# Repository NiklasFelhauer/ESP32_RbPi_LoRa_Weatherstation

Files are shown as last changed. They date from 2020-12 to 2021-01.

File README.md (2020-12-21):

# ESP32_RbPi_LoRa_Weatherstation

hey everyone!

components used: >1xESP32; >1xRaspberry Pi 4 Modell B; >1xBME280 weather sensor; >2xLoRa RFM95 tranceivers

IDE used: Visual Studio Code (Python: Microsoft Python Extension and C: PlatformIO Extension)

What is LoRa? LoRa (Long Range) is a upcoming RF technology that includes features like long range (depends highly on the area, but up to multiple miles) or low power consumption. So perfect for IoT projects like this one here!

description: ESP32 sends weather data (provided by BME280 sensor) via LoRa tranceiver to LoRa tranceiver (=connected to RbPi). Now, here are 2 directions to go: 1) RbPi sends weather data via MQTT network to NodeRed to display the data on a NodeRed dashboard OR 2) RbPi stores weather data in InflxDB (timestamps based database) to visualize the data in grafana

programming language used: mainly C (ESP32) and Python (Raspberry Pi) > (1) in NodeRed simple html, css, JAVA and JSON codes

planned updates: >3D-printed weatherstation case (I'll upload .stl data soon) >supply ESP32 with battery/solar-charger/solar-panel

more details in the specific folders.

stay tuned! :)

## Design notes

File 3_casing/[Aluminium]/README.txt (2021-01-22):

The .stl files for aluminum-components are just for visualization

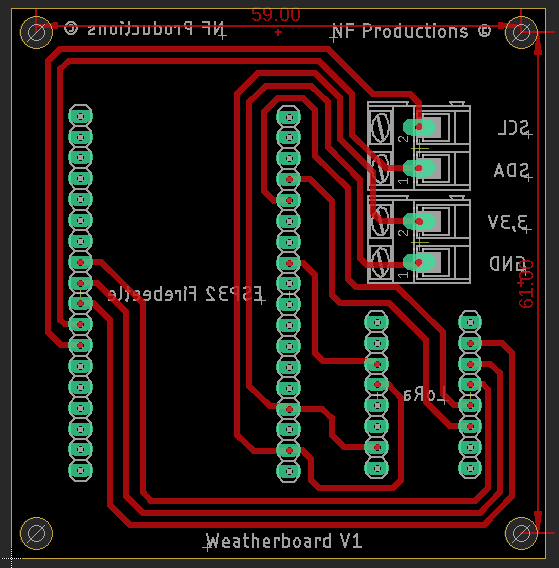
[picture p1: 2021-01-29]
4_circuit_board/Size.PNG

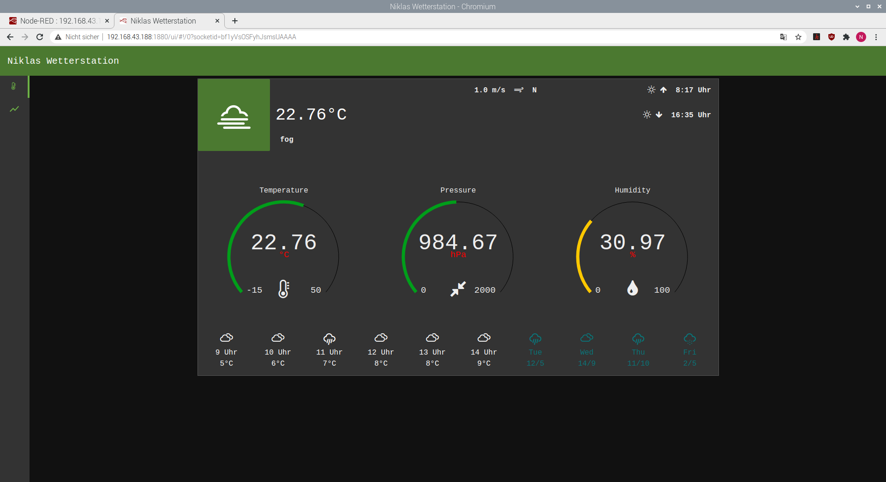
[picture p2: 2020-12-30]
2_MQTT_NodeRed/NodeRed (JSON,JAVA)/example_dashboard.png

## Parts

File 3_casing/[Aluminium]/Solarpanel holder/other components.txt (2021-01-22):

Screws:

x4: M5, 25mm
x1: M5, 30mm
x4: M4, 20mm

------------------

Nuts:

x5: M5

------------------

Aluminium Profiles used:

x2: 20x10x140mm
x1: 20x10x162mm

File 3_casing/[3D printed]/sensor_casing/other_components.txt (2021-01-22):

threaded rods:

x3: M5, 140mm length

Nuts:

x3: M5

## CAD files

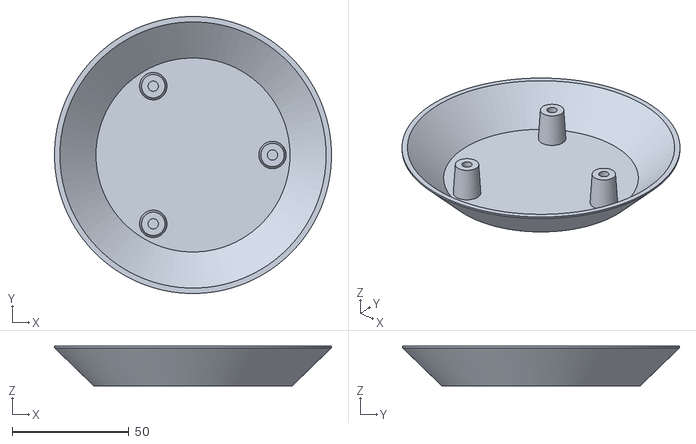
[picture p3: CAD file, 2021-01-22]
3_casing/[3D printed]/sensor_casing/__1x__main_top.stl
118.5 x 118.5 x 17.0

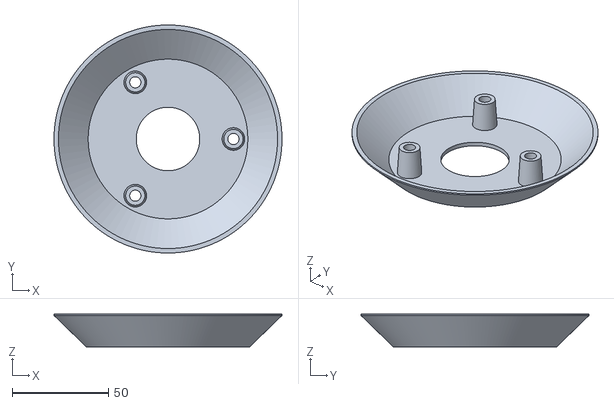
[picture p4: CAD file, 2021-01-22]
3_casing/[3D printed]/sensor_casing/__6x__main.stl
118.5 x 118.5 x 17.0

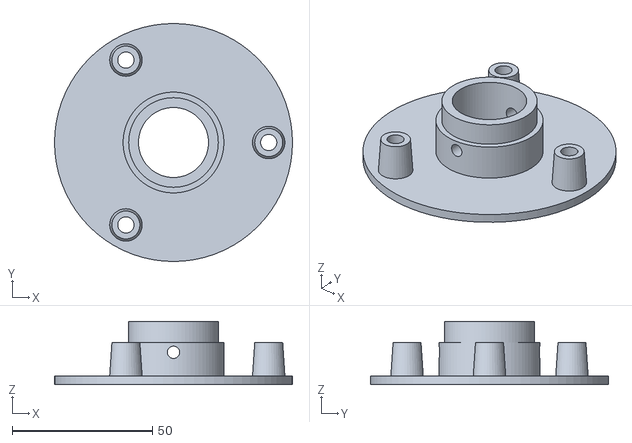
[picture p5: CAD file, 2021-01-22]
3_casing/[3D printed]/sensor_casing/__1x__main_bottom.stl
85.0 x 85.0 x 22.5

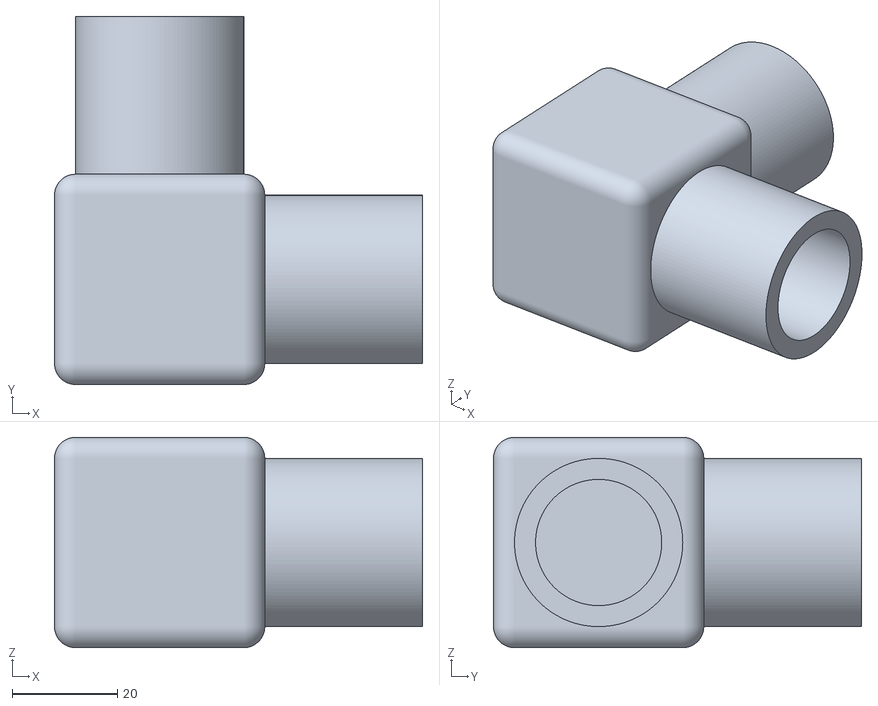
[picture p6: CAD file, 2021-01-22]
3_casing/[3D printed]/connectors/__1x__2_direction_connector.stl
70.0 x 70.0 x 40.0

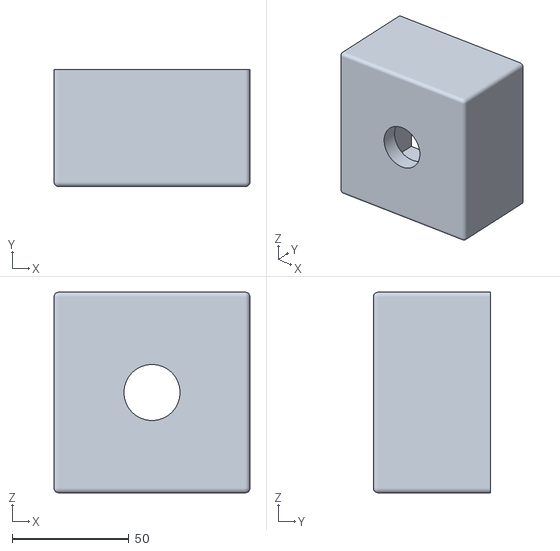
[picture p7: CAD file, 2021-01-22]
3_casing/[3D printed]/controlbox/NF_Box_1.stl
84.0 x 50.2 x 86.0

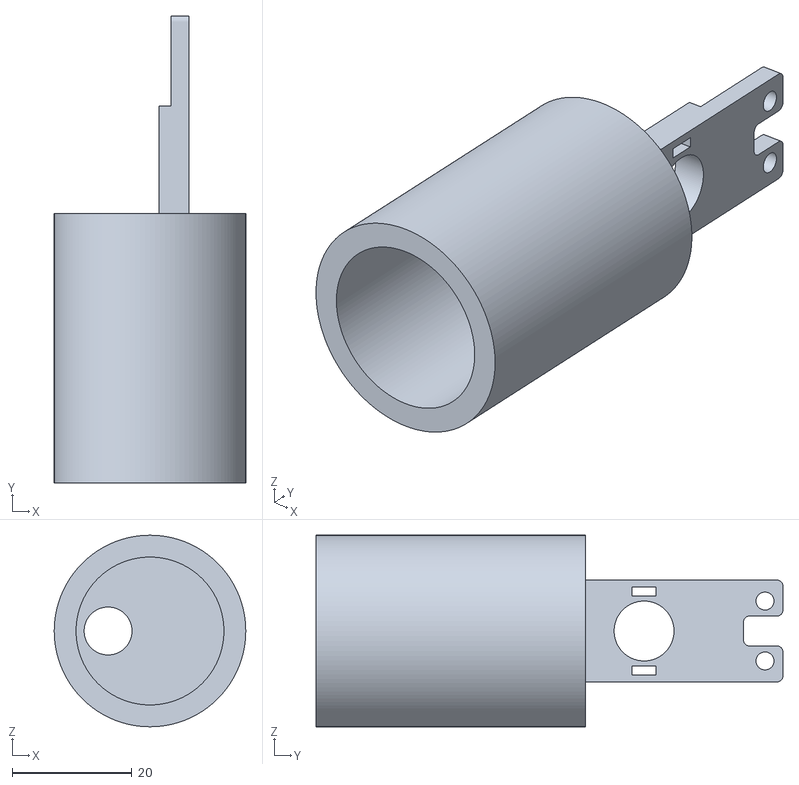
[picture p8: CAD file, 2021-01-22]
3_casing/[3D printed]/sensor_casing/__1x__Sensor_holder_V2.stl
32.0 x 78.0 x 32.0

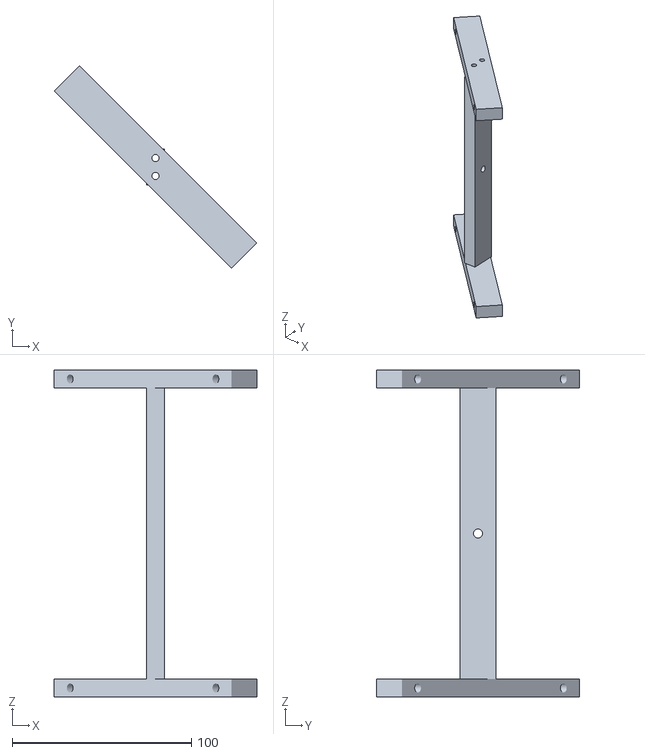
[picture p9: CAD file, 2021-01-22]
3_casing/[Aluminium]/Solarpanel holder/Solarpanel-holder.stl
113.1 x 113.1 x 182.5

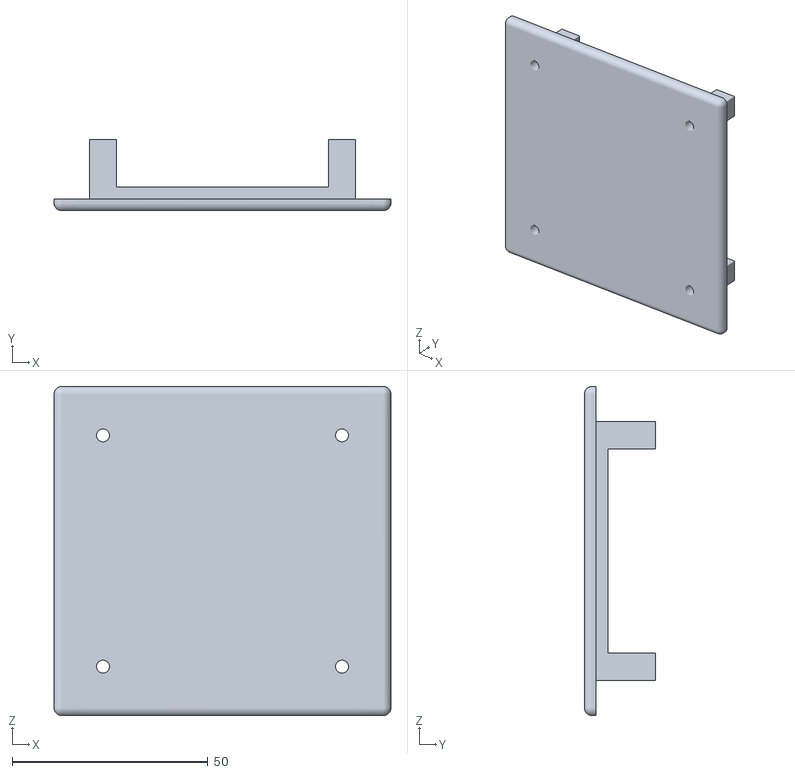
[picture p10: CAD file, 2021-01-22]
3_casing/[3D printed]/controlbox/NF_Box_3.stl
86.0 x 18.2 x 84.0

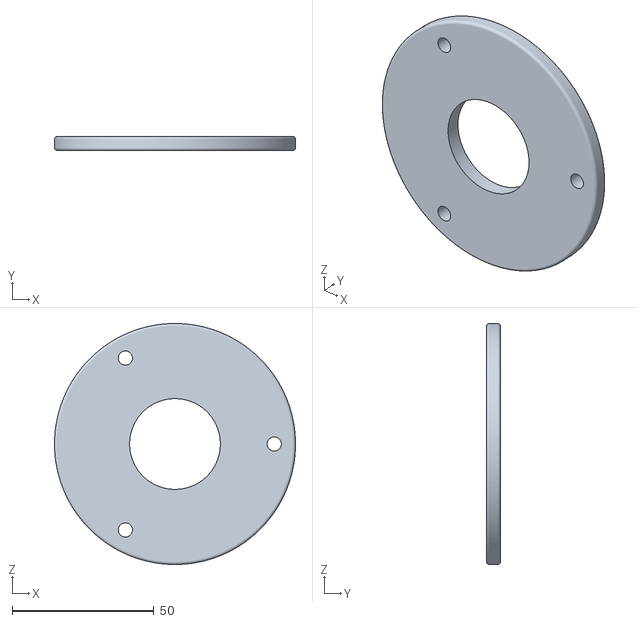
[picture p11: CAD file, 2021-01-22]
3_casing/[3D printed]/sensor_casing/__1x__flange_V2.stl
85.0 x 5.00 x 85.0

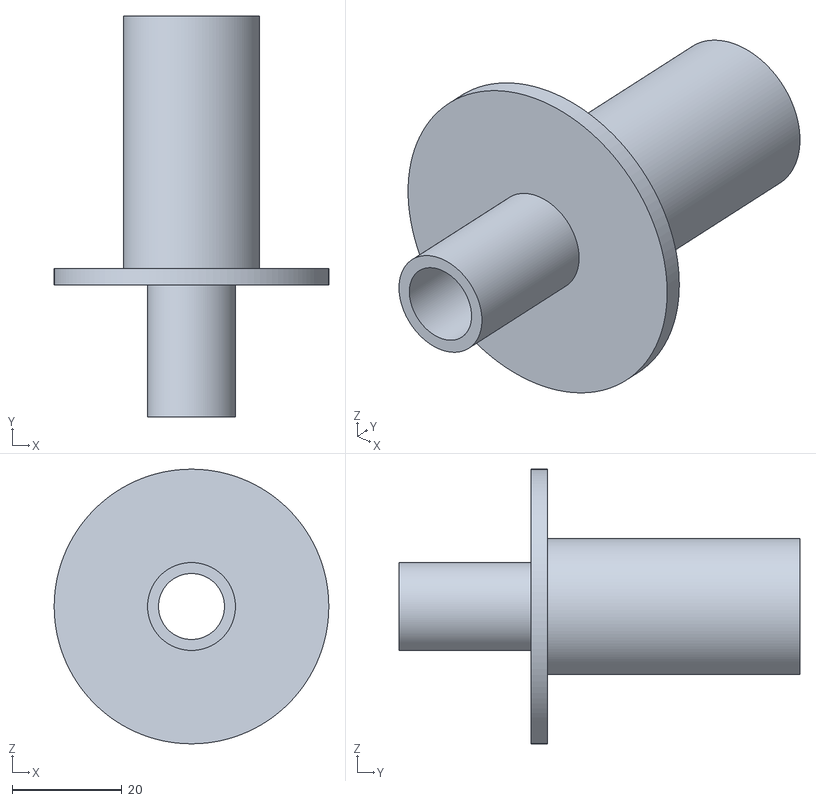
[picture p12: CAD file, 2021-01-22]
3_casing/[3D printed]/sensor_casing/__1x__connector_inside.stl
50.0 x 73.0 x 50.0

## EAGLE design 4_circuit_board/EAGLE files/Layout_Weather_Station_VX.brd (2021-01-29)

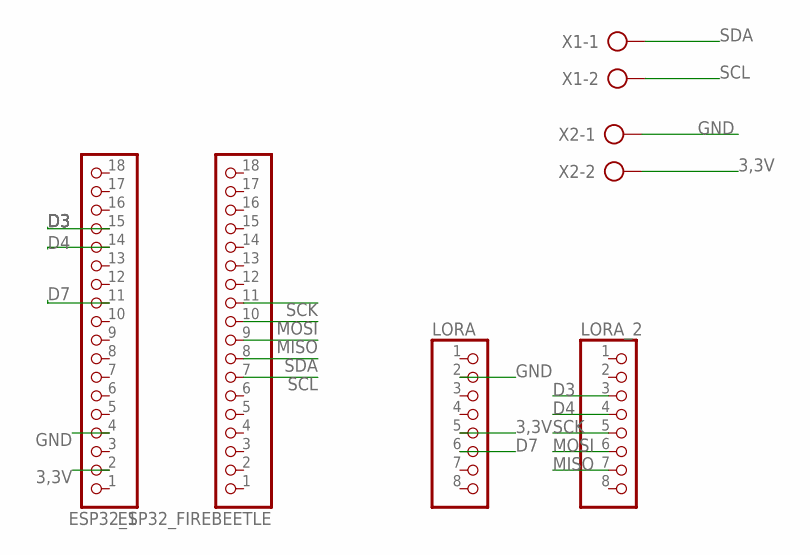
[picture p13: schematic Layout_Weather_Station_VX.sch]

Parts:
ESP32_1, ESP32_FIREBEETLE: PINHD-1X18; 1X18
LORA: PINHD-1X8; 1X08
LORA_2: PINHD-1X8; 1X08
X1, X2: AK300/2

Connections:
3,3V: ESP32_1.2, LORA.5, X2.2
D3: ESP32_1.15, LORA_2.3
D4: ESP32_1.14, LORA_2.4
D7: ESP32_1.11, LORA.6
GND: ESP32_1.4, LORA.2, X2.1
MISO: ESP32_FIREBEETLE.9, LORA_2.7
MOSI: ESP32_FIREBEETLE.10, LORA_2.6
SCK: ESP32_FIREBEETLE.11, LORA_2.5
SCL: ESP32_FIREBEETLE.7, X1.2
SDA: ESP32_FIREBEETLE.8, X1.1

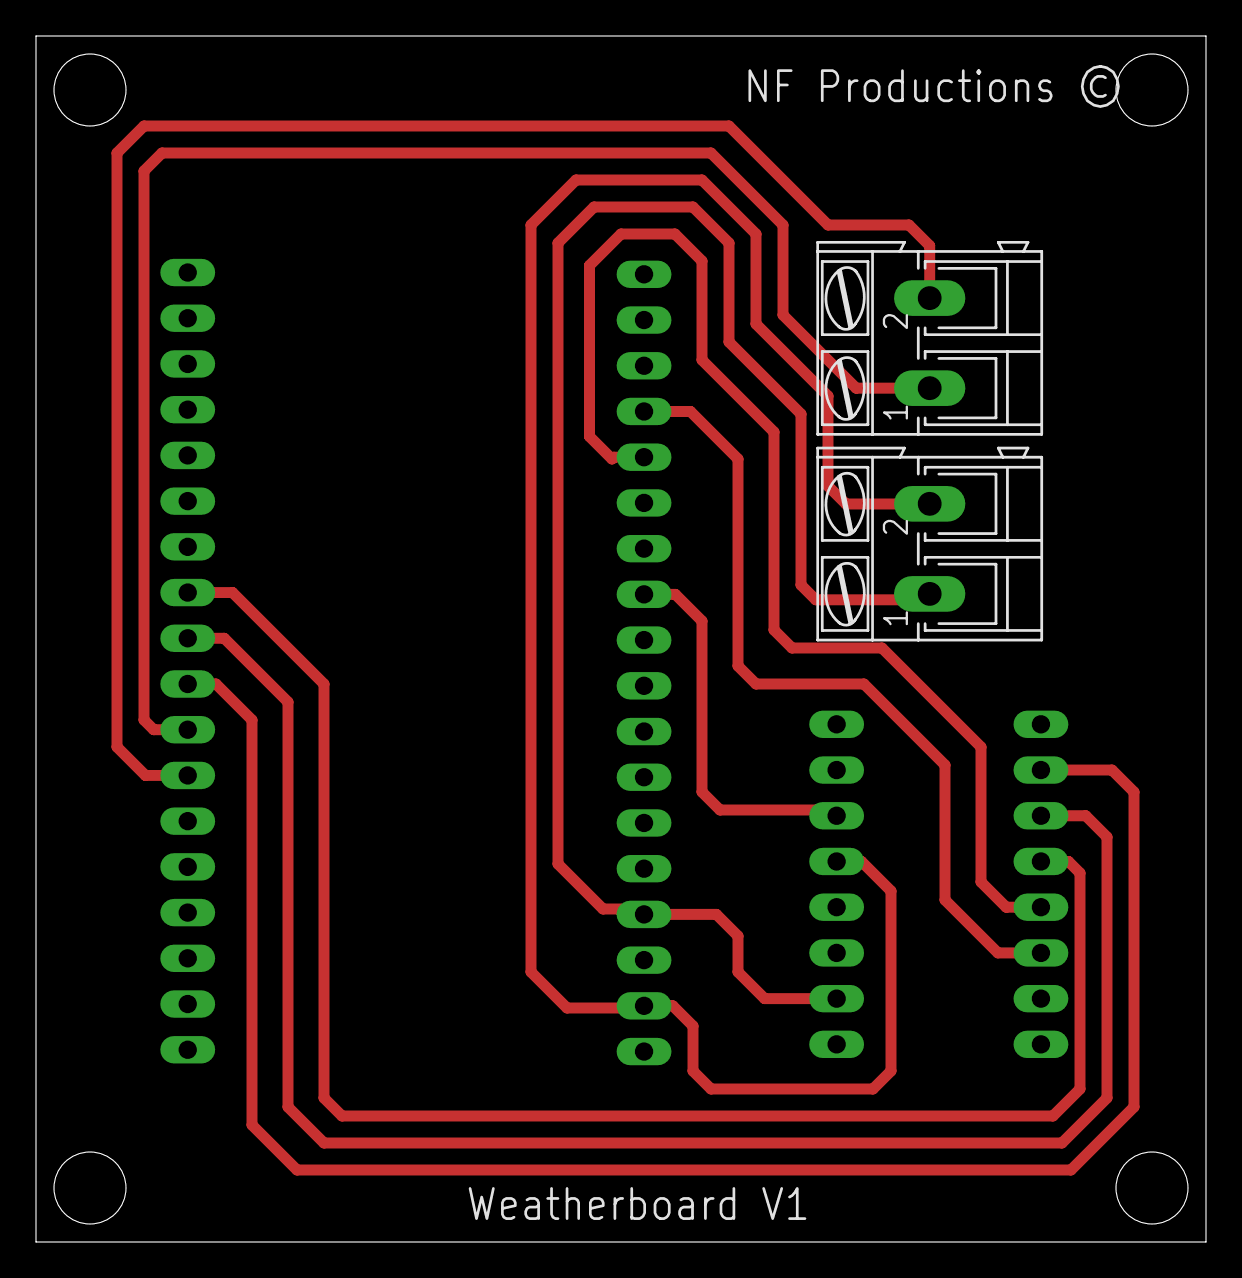
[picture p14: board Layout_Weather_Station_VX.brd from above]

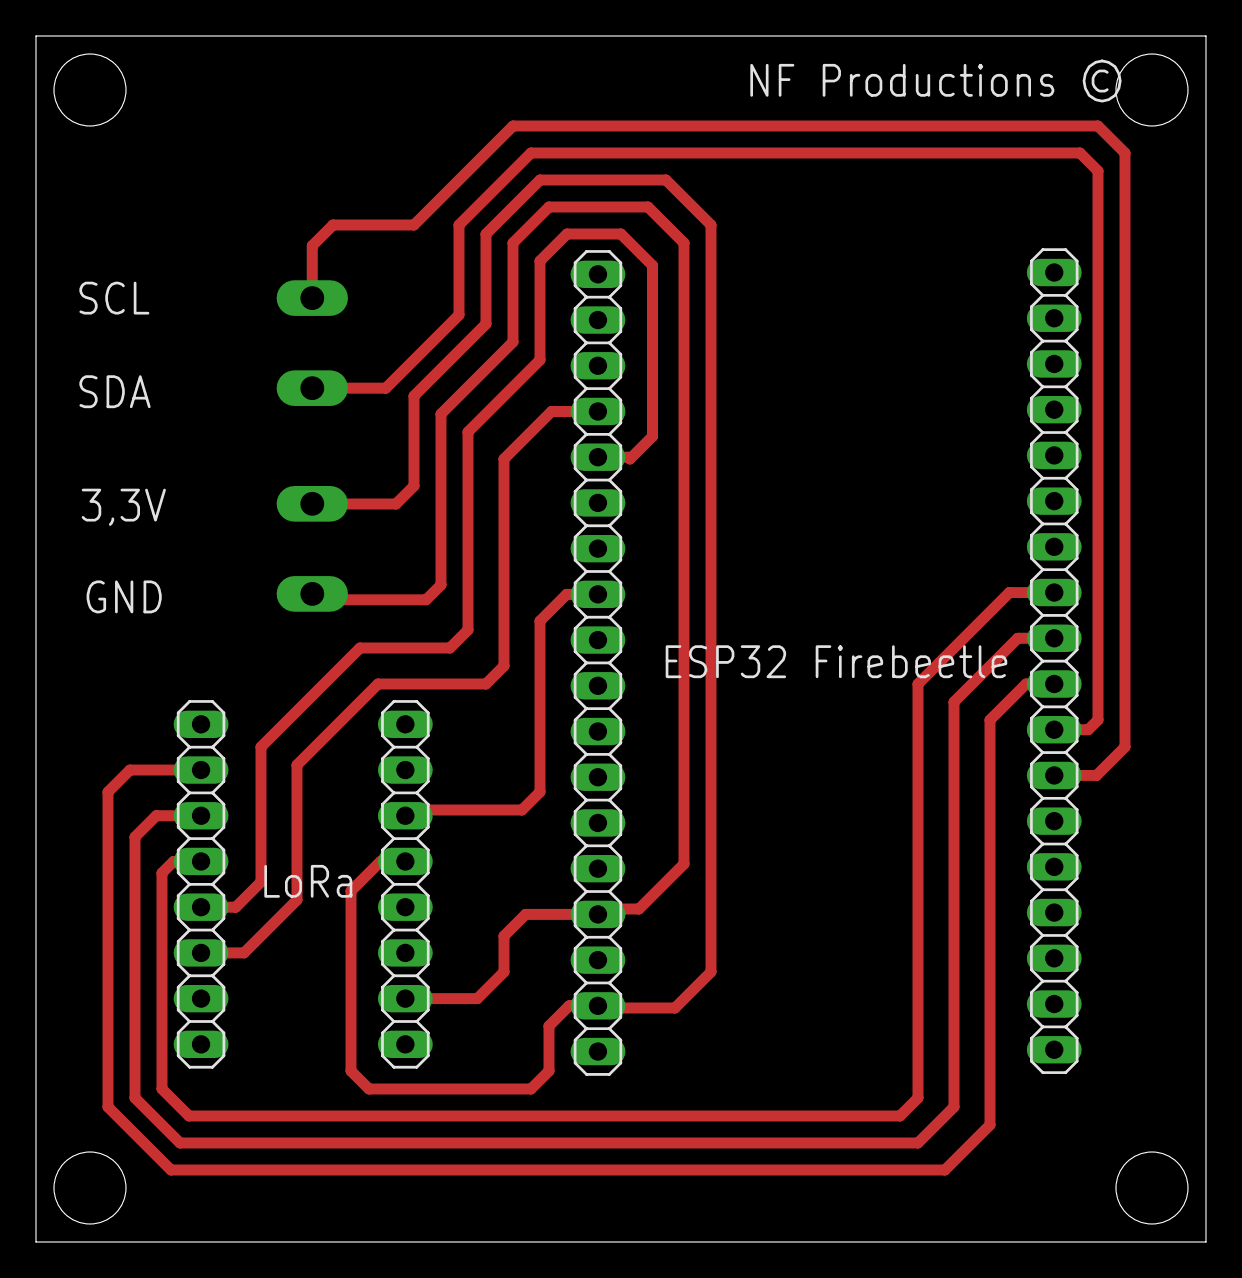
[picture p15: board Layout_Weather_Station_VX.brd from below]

Board: 2 copper layers, 65.0 x 67.0 mm, 6 parts (4 on the bottom side), 10 nets.

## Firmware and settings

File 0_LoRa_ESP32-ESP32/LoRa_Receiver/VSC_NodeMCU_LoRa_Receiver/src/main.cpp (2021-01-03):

/*
============================================================================
title: NodeMCU_LoRa_Receiver
description: sends test packet with counter via LoRa
author: Niklas Felhauer
GitHub: NiklasFelhauer
organization: NF-codes
date: 12/29/2020
version: 0.0
notes: don't forget to write: monitor_speed=115200 in "platformio.ini" 
platformio_version: 5.0.4
============================================================================
*/

//include libraries
#include <Arduino.h>
#include <SPI.h>
#include <LoRa.h> //run this in the terminal to download: pio lib install "sandeepmistry/LoRa"

//define the pins used by the transceiver module
#define ss 5
#define rst 14
#define dio0 2

//===== VOID SETUP =====================================================================

void setup() {
  //initialize Serial Monitor, don't forget to match platformio.ini settings 
  Serial.begin(115200);
  while (!Serial);
  Serial.println("LoRa Tranceiver connected correctly!");

  //setup LoRa transceiver module
  LoRa.setPins(ss, rst, dio0);
  
  //while LoRa tranceiver is connected incorrectly
  //433E6 for 433 MHz (Asia)
  //866E6 for 868 MHz (Europe)
  //915E6 for 915 MHz (America)
  while (!LoRa.begin(866E6)) {
    Serial.println(".");
    delay(500);
  }
  //Sync word assures you don't get LoRa messages from other LoRa tranceivers
  //Sync words of receiver and transmitter have to match
  //chose in range of 0 - 0xFF
  LoRa.setSyncWord(0xF4);
  Serial.println("LoRa Initializing OK!");
}

//===== VOID LOOP =====================================================================

void loop() {
  // try to parse packet
  int packetSize = LoRa.parsePacket();
  if (packetSize) {
    // received a packet
    Serial.print("Received packet '");

    // read packet, it has to be stored in a String
    while (LoRa.available()) {
      String LoRaData = LoRa.readString();
      Serial.print(LoRaData); 
    }
  }
}

//===== END VOID LOOP ===================================================================

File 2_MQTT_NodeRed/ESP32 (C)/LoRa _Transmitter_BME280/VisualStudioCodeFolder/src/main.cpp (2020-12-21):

/*
============================================================================
title: ESP32_BME280_LoRa_Transmitter
description: ESP32 reads weather data from BME280 sensor and them via LoRa.
author: Niklas Felhauer
GitHub: NiklasFelhauer
organization: NF-codes
date: 12/21/2020
version: 0.0
notes: don't forget to write: monitor_speed=115200 in "platformio.ini" 
platformio_version: 5.0.4
============================================================================
*/

#include <Arduino.h>
#include <SPI.h>
#include <Adafruit_BME280.h>
#include <Adafruit_Sensor.h>
#include <LoRa.h>
#include <Wire.h>

//deep sleep settings
#define microseconds_to_seconds 1000000
#define seconds_to_minutes 60
#define TimetoSleep 10

Adafruit_BME280 bme;

//define LoRa tranceiver pins (SPI)
#define ss 5
#define rst 14
#define dio0 2

float temperature;
float humidity;
float pressure;

//===== VOID SETUP =====================================================================

void setup() {
  

  Serial.begin(115200);
  while(!Serial);
  Serial.println(F("searching for BME280 sensor"));

    //while BME280 sensor is connected incorrectly
    while (!bme.begin(0x76) ){
      Serial.print("please check BME280 sensor wiring!\n");
      delay(1000);
   }

  Serial.println(F("searching for LoRa tranceiver module"));
  LoRa.setPins(ss,rst,dio0);

  

    //while LoRa tranceiver is connected incorrectly
    //433E6 for 433 MHz (Asia)
    //866E6 for 868 MHz (Europe)
    //915E6 for 915 MHz (America)
    while (!LoRa.begin(868E6)){
      Serial.print(".");
      delay(500);
    }

  //Sync word assures you don't get LoRa messages from other LoRa tranceivers
  //Sync words of receiver and transmitter have to match
  //chose in range of 0 - 0xFF
  LoRa.setSyncWord(0xF3); 
                           

  Serial.println("\n>> initialization complete <<\n");

  //wake up esp with timer (here: after 10 minutes)
  esp_sleep_enable_timer_wakeup(TimetoSleep * microseconds_to_seconds * seconds_to_minutes);

}

//===== VOID LOOP =====================================================================

void loop() { 
  
  //get temperature
  temperature = bme.readTemperature();
  Serial.printf("Temperature = %.2f *C \n", temperature);
  
  //get pressure
  pressure = bme.readPressure() / 100.0;
  Serial.printf("Pressure = %.2f hPa \n", pressure);

  //get humidity
  humidity = bme.readHumidity();
  Serial.printf("Humidity = %.2f %% \n \n", humidity);
  
  //create LoRa Packet and send it, don't forget to close it again
  LoRa.beginPacket();
    LoRa.print(temperature);
    LoRa.print(pressure); 
    LoRa.print(humidity);
    LoRa.flush();
  LoRa.endPacket();

  //start deep sleep to safe batterie
  esp_deep_sleep_start();
}
//===== END VOID LOOP ===================================================================

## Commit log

2020-12-21 Upload ESP32 Code
2020-12-21 Updated NodeRed part with ESP32 LoRa transmitter Code
2020-12-30 Update raw_code.cpp
    Changed to LoRa packet, for bug fixing in python receiver code.
    The setup didn't work for temperatures below 10 °C or F, now it is fixed!
    [raw_code.cpp]
2020-12-30 Update RbPi_LoRa_InfluxDB_grafana.py
    changed the part where payload_data is spiltted in temp, pressure und humidty so it matches the changes in to transmitter file
2021-01-02 bug_1.1 filtering unrealistic measurment fails (e.g: 3000 °C)
2021-01-02 Python: InfluxDB-RbPi: switched logging level from "INFO" to "Warning"
2021-01-03 Upload: LoRa-Communication-Code between to ESP32 NodeMCUs (BETA Version)
2021-01-13 Updated NodeRed Flow example
2021-01-13 updated NodeRed example flow
2021-01-13 NodeRed JSON example flow update
2021-01-22 UPLOAD: most of the casing .stl files.
    [NF_Box_1.stl, NF_Box_3.stl, Solarpanel-holder.stl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]
2021-01-23 UPDATE: NodeRed ESP32 raw code
    included delimiter ";" between each LoRa message to split it later on
2021-01-23 UPDATE
    changed temp/humidity/pressure to individual MQTT topics
2021-01-29 UPLOAD: circuit board EAGLE files
    [Layout_Weather_Station_VX.brd, Layout_Weather_Station_VX.sch]
